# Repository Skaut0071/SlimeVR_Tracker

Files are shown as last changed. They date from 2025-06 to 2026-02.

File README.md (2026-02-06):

# SlimeVR DIY Project

## Overview
This is a DIY project based on the official SlimeVR documentation. The design is created for educational and hobbyist purposes.

### Visuals
<h2 align="center"><b>Front side:</b></h2>

<p align="center">
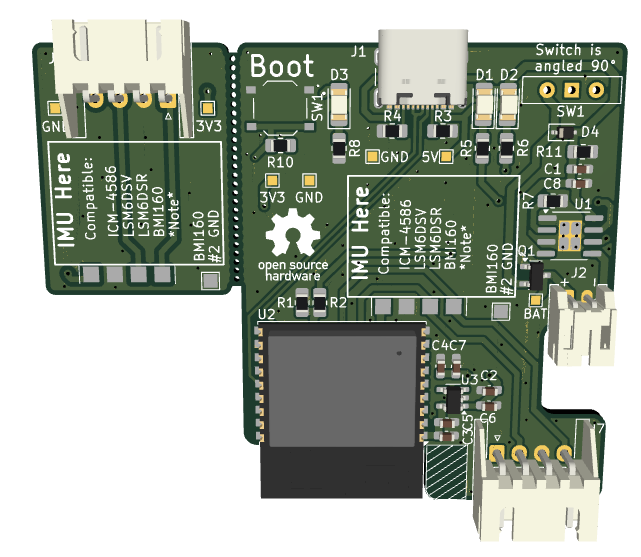
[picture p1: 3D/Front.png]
Front PCB
  
</p>

<h2 align="center"><b>Back side:</b></h2>

<p align="center">
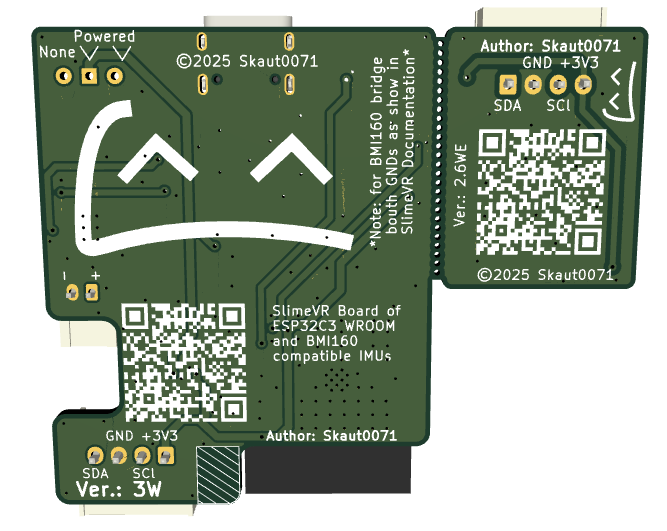
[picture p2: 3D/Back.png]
Back PCB
  
</p>

<h2 align="center"><b>Case:</b></h2>

<p align="center">
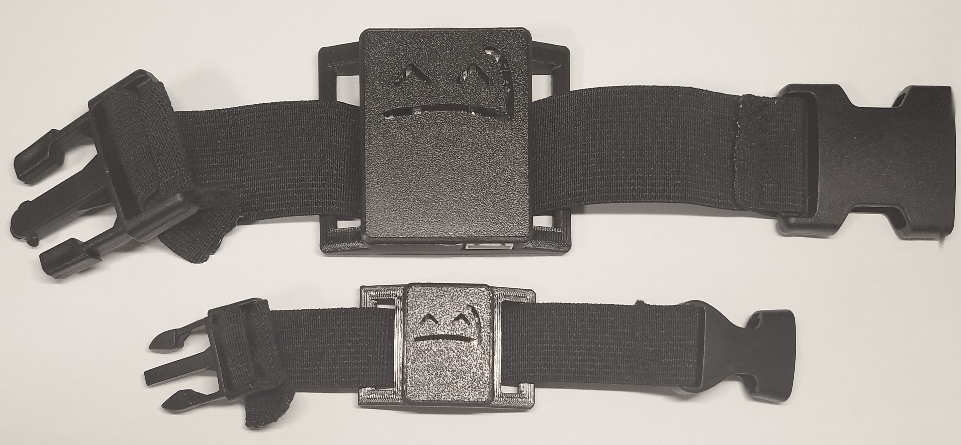
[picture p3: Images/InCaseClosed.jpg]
Case
  
</p>

## Project Information
- **KiCad Version:** 9.0
- **PCB Version:** 3W + 2.6WE (older *bigger* board files are saved if you want them *Version 0.7*, *Version 0.9* and *Version 2.5W*)

  > *W:* = Wireless
  
  > *E:* = Extension

- **Schematic Version:** 2.0
- **Project Type:** DIY/Hobby
- **Manufacture:** JLCPCB

### Hardware Specifications
- **MCU:** ESP32C3 WROOM 02
- **Supported IMU:** Any with same pin out as BMI160 module (*reference at end*)
- **Battery Management:** Integrated TP4056 charging circuit
- **Features:** Battery monitoring (Firmware), Power switch, Status LEDs

### Firmware
- *Will be available when fully tested as functional*

## Disclaimer
⚠️ **Functionality is not guaranteed.** This is an experimental project and may contain errors or issues. Use at your own risk.
- Also there can be a few grafical and speling mistakes so be aware of it.
- The images are for reference only until new version arrives, I will make new ones after

## Design Files
- PCB layout and schematic files are included in this repository
- Based on official SlimeVR documentation and specifications

## Bill of Materials (BOM)
Detailed interactive list of components:
👉 **[Open Interactive BOM (ibom.html)](https://skaut0071.github.io/SlimeVR_Tracker/PDFs/ibom)**

## Contributing
Feel free to submit issues, suggestions, or improvements via GitHub issues or pull requests.

## References
- [Official SlimeVR Documentation](https://docs.slimevr.dev/)
- [SlimeVR GitHub](https://github.com/SlimeVR)
- [BMI160 Module](https://www.aliexpress.com/item/1005006351402967.html)

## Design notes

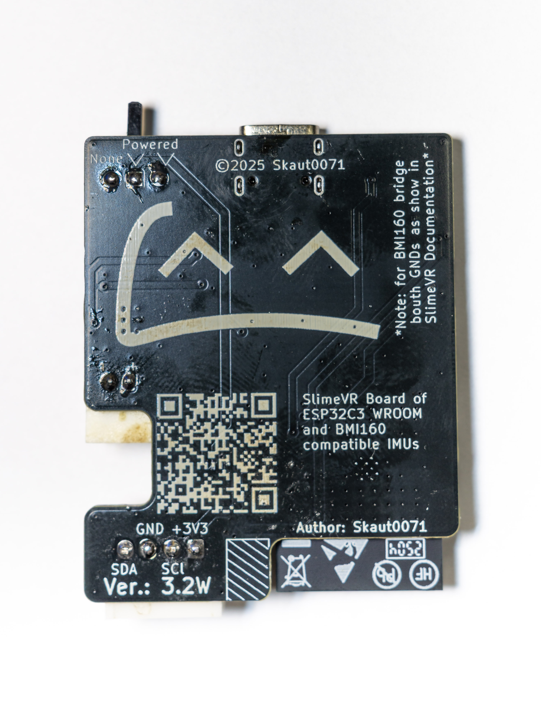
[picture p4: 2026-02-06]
Images/PCBBack.jpg

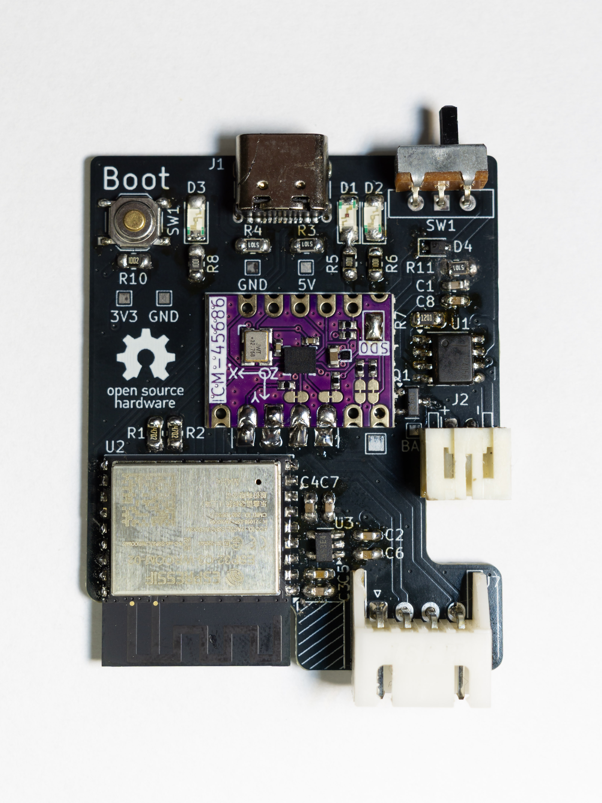
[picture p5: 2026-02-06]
Images/PCBFront.jpg

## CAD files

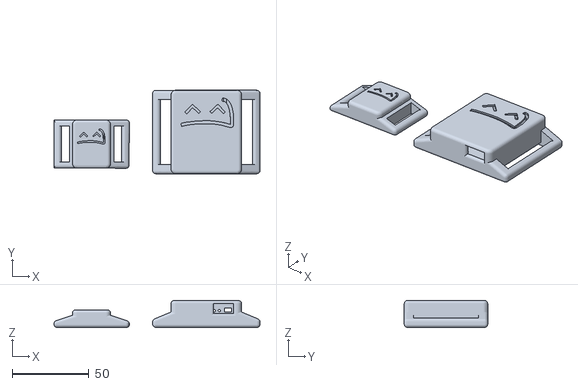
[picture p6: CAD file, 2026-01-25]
3D/SlimeVR Tracker by Skaut0071.stl
134.0 x 54.3 x 17.6

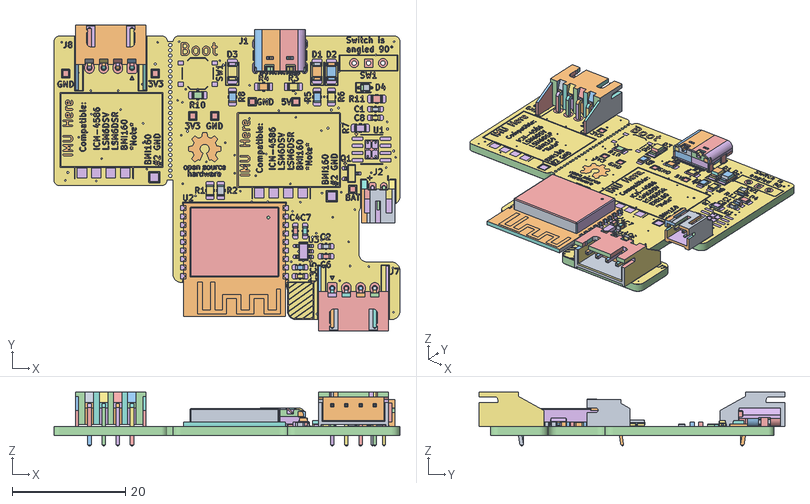
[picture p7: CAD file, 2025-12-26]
3D/SlimeVR_board.obj
61.0 x 54.0 x 9.50
obj1
obj2
obj3
obj4
obj5
obj6
obj7
obj8
obj9
obj10
obj11
obj12
obj13
obj14
obj15
obj16
obj17
obj18
obj19
obj20
obj21
obj22
obj23
obj24
obj25
obj26
obj27
obj28
obj29
obj30
obj31
obj32
obj33
obj34
obj35
obj36
obj37
obj38
obj39
obj40
obj41
obj42
obj43
obj44
obj45
obj46
obj47
obj48
obj49
obj50
obj51
obj52
obj53
obj54
obj55
obj56
obj57
obj58
obj59
obj60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

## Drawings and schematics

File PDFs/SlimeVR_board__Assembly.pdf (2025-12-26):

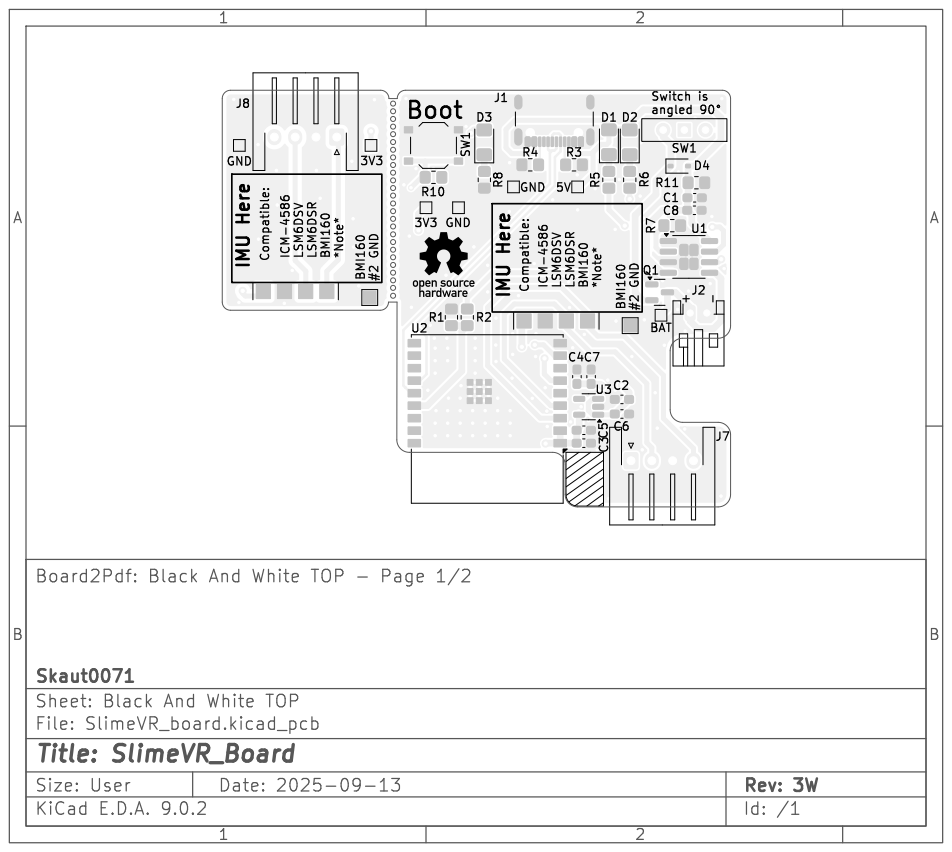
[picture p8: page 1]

IMU Here Compatible: ICM-4586 LSM6DSV LSM6DSR BMI160 *Note*

# \/ \/ Ver.: 3W

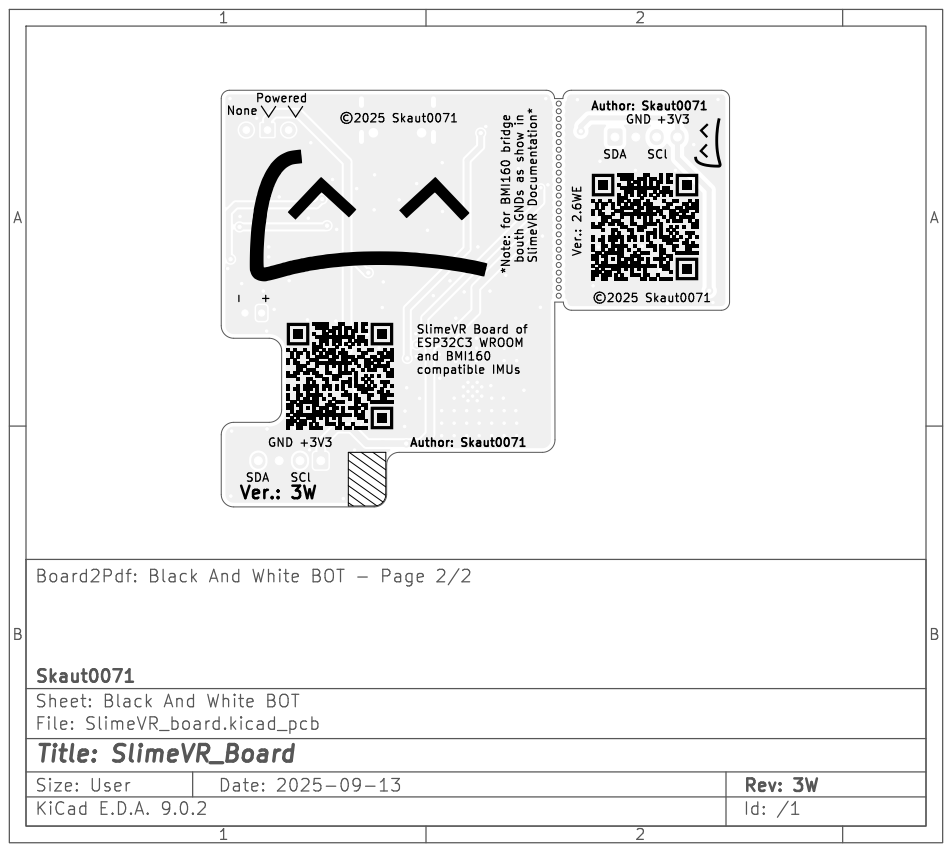
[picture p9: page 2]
Author: Skaut0071 þÿ©2025Skaut0071 +3V3; SCl; SlimeVR Board of ESP32C3 WROOM; and BMI160; compatible; IMUs +3V3; Author: Skaut0071; SDA; Powered; þÿ©2025Skaut0071 SDA; SCl *Note: for BMI160 bridge bouth GNDs as show in SlimeVR Documentation* 1; B Date: 2025-09-13 KiCad; E.D.A. 9.0.2 Size: User; Rev: 3W; Id: /1 Title: SlimeVR_Board; File: SlimeVR_board.kicad_pcb Sheet:; Black; And; White; BOT Skaut0071 Board2Pdf:; And White; BOT -; Page 2/2

-+ GND Ver.: 2.6WE None GND

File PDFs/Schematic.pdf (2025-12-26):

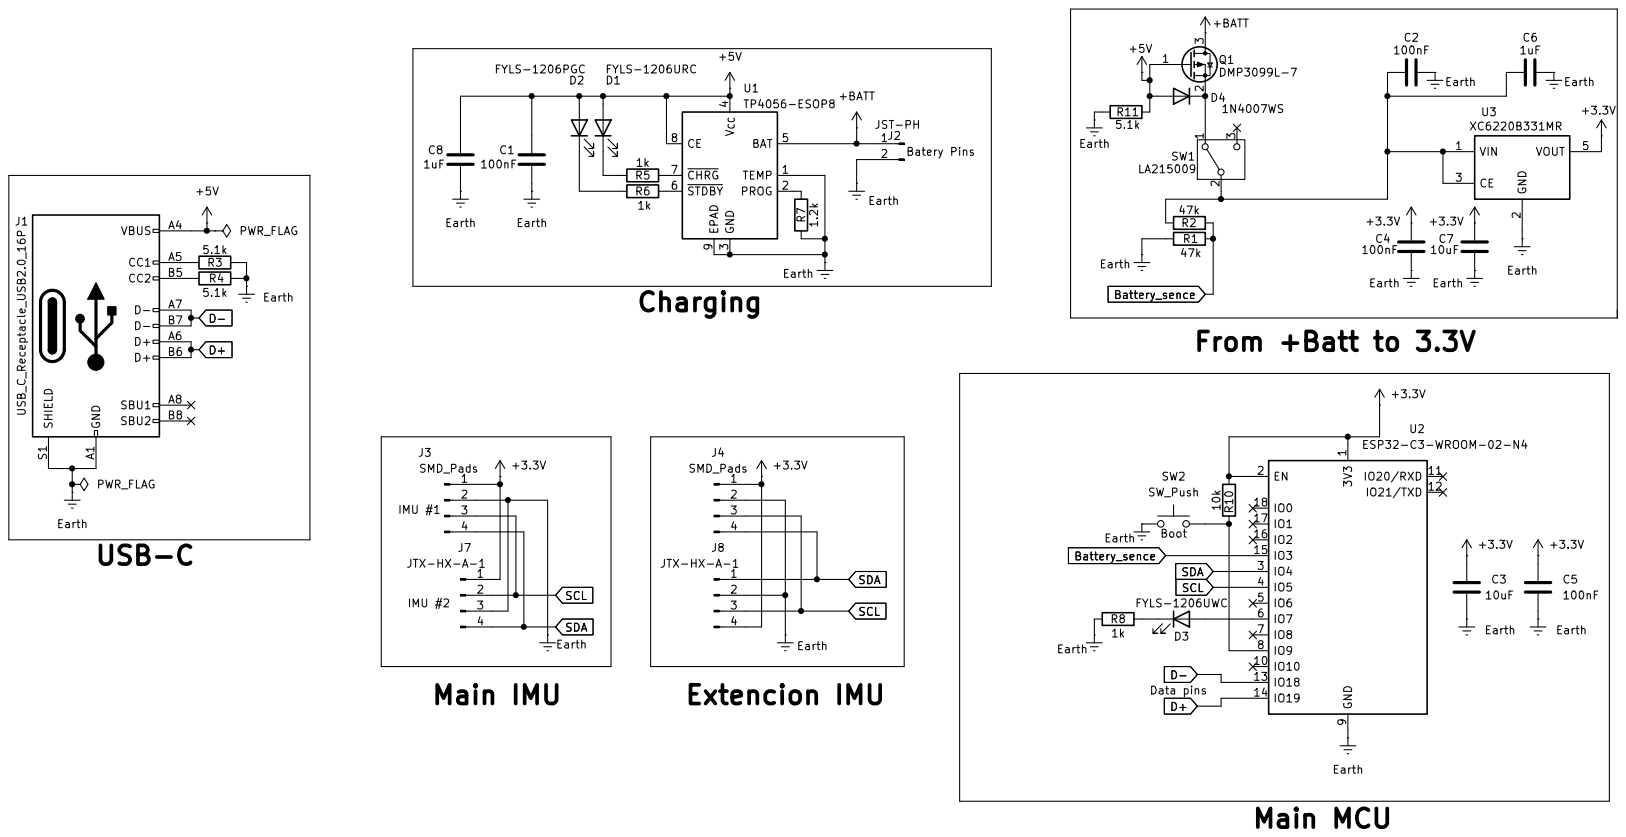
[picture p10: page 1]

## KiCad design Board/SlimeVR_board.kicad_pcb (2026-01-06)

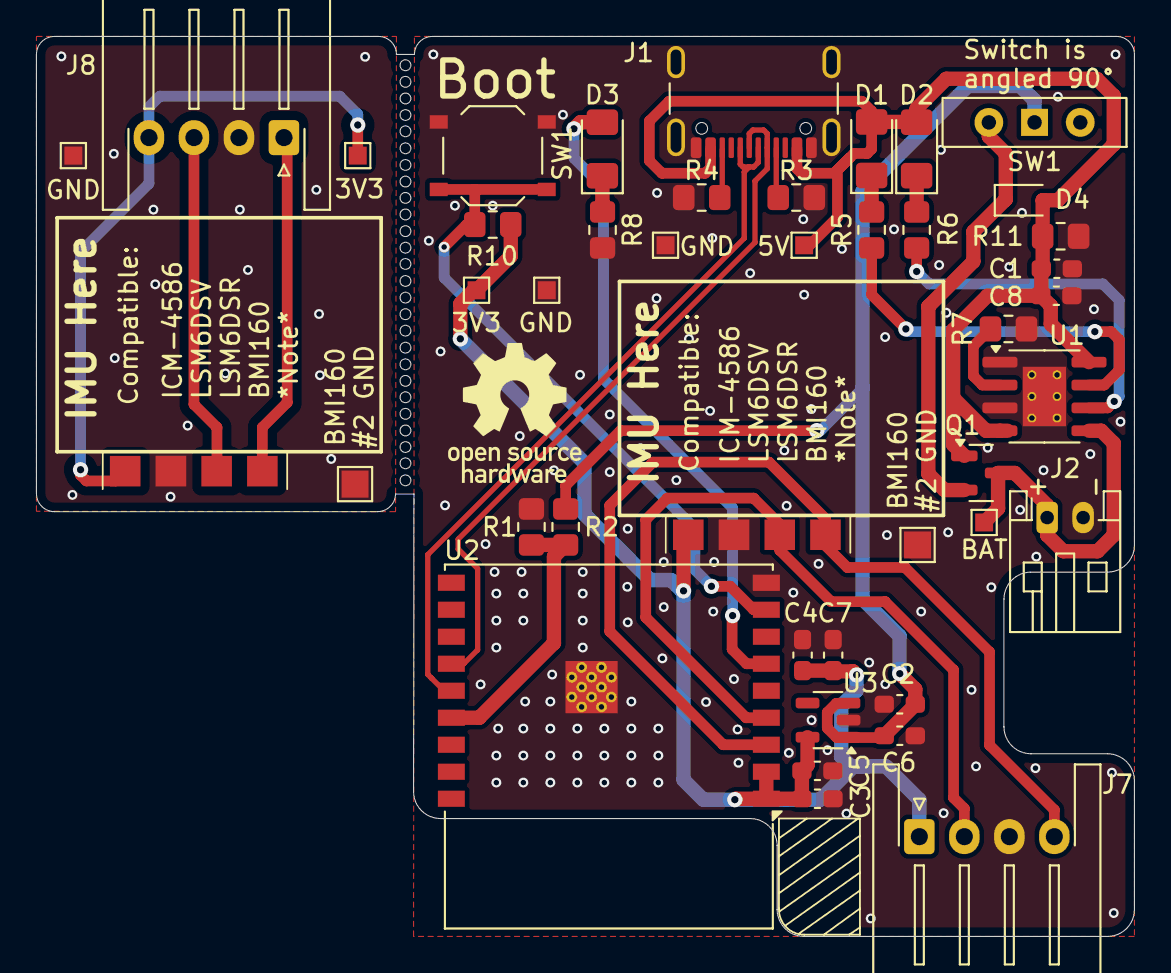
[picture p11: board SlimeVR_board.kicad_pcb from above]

Board: 2 copper layers, 61.0 x 50.0 mm, 43 parts (0 on the bottom side), 21 nets.

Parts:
3V3, 3V3#2, 5V: TestPoint_Pad_1.0x1.0mm
BAT: TestPoint_Pad_1.0x1.0mm
BMI160
#2 GND, BMI160
#2 GND#2: TestPoint_Pad_1.5x1.5mm
C1, C2, C4, C5: 100nF; C_0603_1608Metric_Pad1.08x0.95mm_HandSolder
C3, C7: 10uF; C_0603_1608Metric_Pad1.08x0.95mm_HandSolder
C6, C8: 1uF; C_0603_1608Metric_Pad1.08x0.95mm_HandSolder
D1: FYLS-1206URC; LED_1206_3216Metric_Pad1.42x1.75mm_HandSolder
D2: FYLS-1206PGC; LED_1206_3216Metric_Pad1.42x1.75mm_HandSolder
D3: FYLS-1206UWC; LED_1206_3216Metric_Pad1.42x1.75mm_HandSolder
D4: 1N4007WS; D_SOD-323
GND: TestPoint_Pad_1.0x1.0mm
GND#2, GND#3: TestPoint_Pad_1.0x1.0mm
J1: USB_C_Receptacle_USB2.0_16P; USB_C_Receptacle_GCT_USB4105-xx-A_16P_TopMnt_Horizontal
J2: JST-PH; JST_PH_S2B-PH-K_1x02_P2.00mm_Horizontal
J3, J4: SMD_Pads; Pin_1x04_SMD_P2.54mm
J7, J8: JTX-HX-A-1; JST_XH_S4B-XH-A-1_1x04_P2.50mm_Horizontal
Q1: DMP3099L-7; SOT-23
R1, R2: 47k; R_0805_2012Metric_Pad1.20x1.40mm_HandSolder
R3, R4, R11: 5.1k; R_0805_2012Metric_Pad1.20x1.40mm_HandSolder
R5, R6, R8: 1k; R_0805_2012Metric_Pad1.20x1.40mm_HandSolder
R7: 1.2k; R_0805_2012Metric_Pad1.20x1.40mm_HandSolder
R10: 10k; R_0805_2012Metric_Pad1.20x1.40mm_HandSolder
SW1: LA215009; SW_Slide-03_Wuerth-WS-SLTV_10x2.5x6.4_P2.54mm
SW2: SW_Push; SW_Push_1P1T_XKB_TS-1187A
U1: TP4056-ESOP8; SOIC-8-1EP_3.9x4.9mm_P1.27mm_EP2.41x3.3mm_ThermalVias
U2: ESP32-C3-WROOM-02-N4; ESP32-C3-WROOM-02
U3: XC6220B331MR; SOT-23-5

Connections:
+3.3V: 3V3.1, 3V3#2.1, C3.1, C4.1, C5.1, C7.1, J3.1, J4.1, J7.1, J8.4, R10.1, U2.1 (3V3), U2.2 (EN), U3.5 (VOUT)
+5V: 5V.1, C1.1, C8.1, D1.2 (A), D2.2 (A), D4.2 (A), J1.A4 (VBUS), J1.A9 (VBUS), J1.B4 (VBUS), J1.B9 (VBUS), Q1.1 (G), R11.2, U1.4 (V_{CC}), U1.8 (CE)
+BATT: BAT.1, J2.1, Q1.3 (D), U1.5 (BAT)
Battery_sence: R1.1, R2.2, U2.15 (IO3)
D+: J1.A6 (D+), J1.B6 (D+), U2.14 (IO19)
D-: J1.A7 (D-), J1.B7 (D-), U2.13 (IO18)
Earth: BMI160 #2 GND.1, BMI160 #2 GND#2.1, C1.2, C2.2, C3.2, C4.2, C5.2, C6.2, C7.2, C8.2, GND.1, GND#2.1, GND#3.1, J1.A1 (GND), J1.A12 (GND), J1.B1 (GND), J1.B12 (GND), J1.S1 (SHIELD), J2.2, J3.2, J4.2, J7.3, J8.2, R1.2, R3.2, R4.1, R7.2, R8.1, R11.1, SW2.1, U1.1 (TEMP), U1.3 (GND), U1.9 (EPAD), U2.9 (GND), U2.19 (GND), U3.2 (GND)
unnamed: D1.1 (K), R5.1
unnamed: D2.1 (K), R6.1
unnamed: D3.2 (A), U2.6 (IO7)
unnamed: D3.1 (K), R8.2
unnamed: D4.1 (K), Q1.2 (S), SW1.1 (A)
unnamed: J1.A5 (CC1), R3.1
unnamed: J1.B5 (CC2), R4.2
unnamed: C2.1, C6.1, R2.1, SW1.2 (B), U3.1 (VIN), U3.3 (CE)
unnamed: R7.1, U1.2 (PROG)
unnamed: R5.2, U1.7 (~CHRG)
unnamed: R6.2, U1.6 (~STDBY)
unnamed: R10.2, SW2.2, U2.8 (IO9)
SCL: J3.3, J4.3, J7.2, J8.3, U2.4 (IO5)
SDA: J3.4, J4.4, J7.4, J8.1, U2.3 (IO4)

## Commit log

2025-06-15 New Version
    skiped few version that ware bad or not good or not funcioning
    [SlimeVR_board.kicad_pcb, SlimeVR_board.kicad_sch]
2025-06-15 Uploaded custom footprints
2025-06-15 Added board blueprint and material list
2025-06-15 Uploaded old PCB
    [SlimeVR_board_Full.kicad_pcb]
2025-07-02 New version
    [SlimeVR_board.kicad_pcb, SlimeVR_board.kicad_sch]
2025-07-02 Newest verison
    [SlimeVR_board.obj]
2025-07-02 New older version avaible
    [SlimeVR_board_Conpact.kicad_pcb]
2025-07-02 New Schematic PDF
2025-07-02 New Grep files
    [SlimeVR_board-B_Cu.gbr, SlimeVR_board-B_Mask.gbr, SlimeVR_board-B_Silkscreen.gbr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]
2025-09-08 New version of board
    Fixex:
    - grafical issues and speling
    - wrong diode used, board wont get more then 150mA
    - battery pins has been swaped for standarizes conection
    [SlimeVR_board.kicad_pcb, SlimeVR_board.kicad_sch]
2025-09-08 New 3D models for new board
    [SlimeVR_board.obj]
2025-09-08 New greb files for new board
    [SlimeVR_board-B_Cu.gbr, SlimeVR_board-B_Mask.gbr, SlimeVR_board-B_Silkscreen.gbr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]
2025-09-08 New PDFs for new board
2025-09-09 Fix labels
    - Fix wrong labels position at battery conetion
    [SlimeVR_board.kicad_pcb]
2025-09-13 Nweset Board update
    Update log:
    - Moved 3.3 conventor closer to esp for more stability
    - Properly labeled Boot and Reset pads with own GND
    - New and remade grafic
    - Two capacitators no more needed (material saving :D)
    - New Logo (I got some logo of my probebly will change idk)
    [SlimeVR_board-B_Cu.gbr, SlimeVR_board-B_Mask.gbr, SlimeVR_board-B_Silkscreen.gbr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]
2025-09-13 Newest board models
    (they didnt uploaded from last update)
2025-09-13 Delete 3D/SlimeVR_board.obj
    same as last one...
    [SlimeVR_board.obj]
2025-09-13 Newest board uptade
    )idk why it must be like this)
    [SlimeVR_board.obj]
2025-09-13 Newest board update
    I am dumb, I forgot to create new models :D
    [SlimeVR_board.obj]
2025-11-13 Update pcb and inproved a bit schematic
    [SlimeVR_board.kicad_pcb, SlimeVR_board.kicad_sch]
2025-12-26 Redisign, Power Supply improved
    Removed reset pin becuse just hardware off > on
    Added physical button for boot
    HT7833 replaced for XC6220B331MR becuse HT7833 not working :(
    Small design silkscreen changes
    [SlimeVR_board-B_Cu.gbr, SlimeVR_board-B_Mask.gbr, SlimeVR_board-B_Silkscreen.gbr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]
2026-01-06 Fix formatting in README for Supported IMU section
2026-01-06 Fix link path for Interactive BOM in README
2026-01-06 Update BOM link to use GitHub Pages URL
2026-01-06 Fix formatting of BOM link in README
2026-01-06 Updated pcb
    Fixed pull up rezistor not connected
    Fixed small conection of 5V to LDO
    [SlimeVR_board-B_Cu.gbr, SlimeVR_board-B_Mask.gbr, SlimeVR_board-B_Silkscreen.gbr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]
2026-01-06 Fixed iBom
    Removed unused colum Sim.Device
2026-01-07 Add case image and enhance project details
    Added case image and updated project information.
2026-01-09 Add width and height to case image in README
    Updated image tag to include width and height attributes.
2026-01-25 3D model krabičky
    [SlimeVR Tracker by Skaut0071.stl]
